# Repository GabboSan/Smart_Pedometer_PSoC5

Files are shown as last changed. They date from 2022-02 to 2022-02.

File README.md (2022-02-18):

# AY2022 I Project-1

Smart Pedometer project developed in a MSc Course of Politecnico di Milano:
Authors: 
1. Santicchi Gabriele
2. d'Arenzo Daniele 
3. Santini Matteo

In this work a PSoC CY8C5888LTI-LP097 communicates by I2C protocol with MPU9250, SSD1306, 24LC512 and by UART protocol with HC-06 Bluetooth.\
A PyQt5 GUI has been developed to upload sessions and set user credential.

## Aim of this Work

1. Implement a pedometer algorithm capable to identify and count steps online;
2. Exploit the over-threshold events interrupt of the MPU9250 to automatically wake up the device from sleep; go to sleep mode when no motion is detected for 1 minute;
3. Display in the GUI some statistics: total number of steps, average cadence, total activity time and the session path with respect to the origin (i.e. first 'step' detected);
4. Log the statistics of each session (i.e., of every walk detected) in the internal EEPROM of the PSoC;
5. Minimization of power consumption, by using powersaving functionalities of the PSoC (e.g., Alternate mode) as well as turining off external peripherals when not in use;
6. When connected via USB to the computer, the device can accept a data request and display/send the data stored into the EEPROM.

## MPU9250 and AHRS filtering

To keep track of the direction of the walk, the AHRS filter has been implemented to get a Roll-Pitch-Yaw estimate. As the filter needs the magnetometer measurements, the AK8963 is enabled and set as Slave on the I2C bus.
Each 2 seconds the pedometer algorithm compute the X and Y direction of the walk, by considering the RPY orientation of the device.
The two directions are saved as 16 bit and then saved into the cell of the EEPROM . Path is reconstructed by the PC through this relative coordinates system.

## EEPROM Session Data Structure

When no motion has been detected for 1 minute, the Wake-On-Motion (WOM) interrupt is enabled and session data are saved in the EEPROM with the following structure.\
**RESERVED CELL REGISTERS:**
* 0: Height;
* 1: UserID;
* 2: SessionID;
* 3-4: lastAddressEEPROM: to avoid data overwriting;

**CELL REGISTERS:**

From 24LC512 Datasheet, Read and Write max. operation number is limited to a Page size, which consist of 128 bytes. The Packets to be sent to the PC are structured as:

* UserID, SessionID, HEADER (0xFE,0xFF);
* dataXY: sequence of X and Y relative coordinates (in 16 bits) computed each 2 seconds;
* Number of Steps, TAIL (0xFF,0xFF);

## SSD1306 Display

The SSD1306 communicates by I2C with the Master. It displays the total step counter and the current speed (in cm/s) each 2 seconds. When the device enters in Sleep mode, the display is turned off.

## Final PCB ad Case
<p float="left">
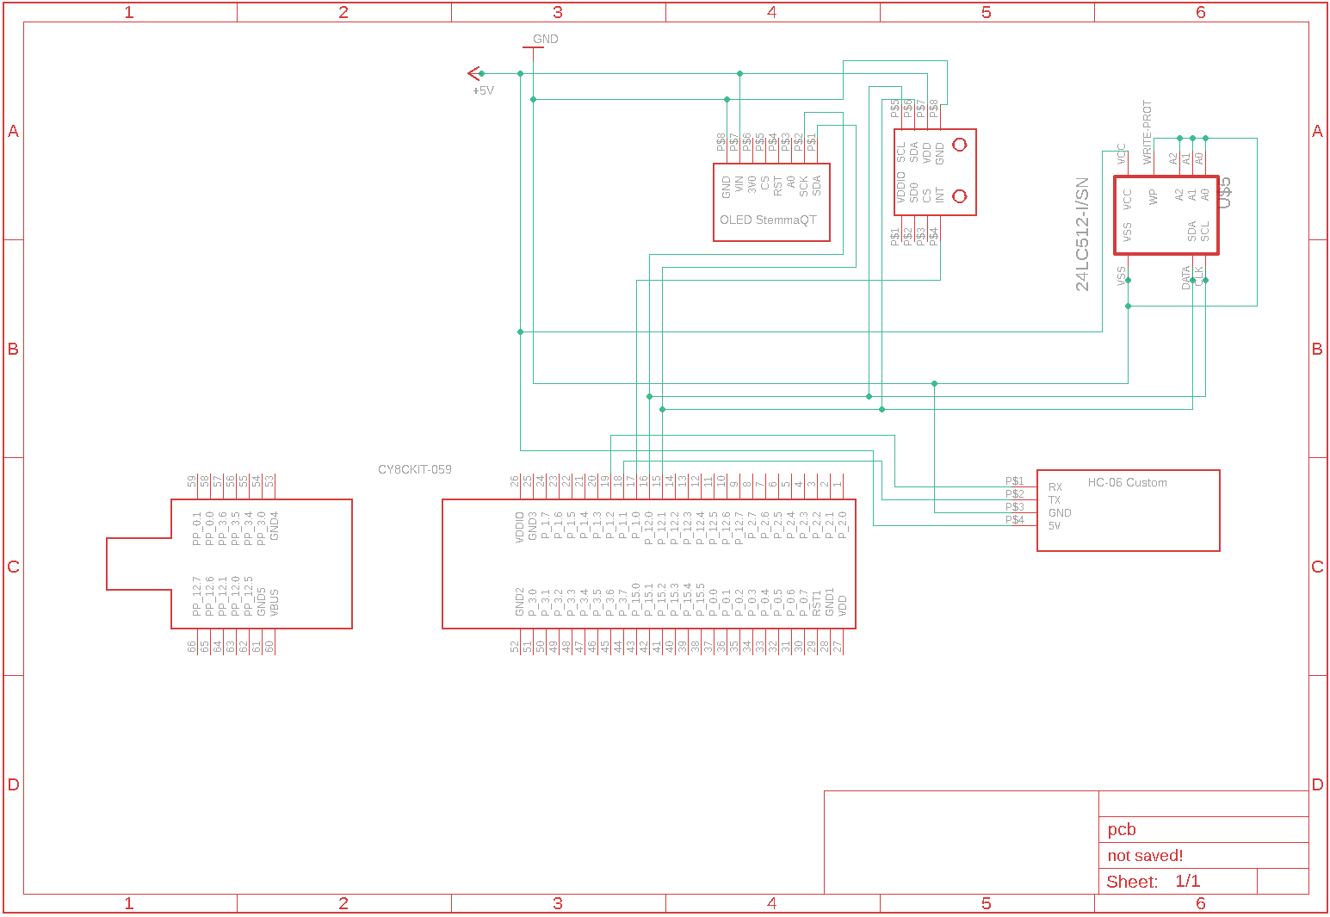
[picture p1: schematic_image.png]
  
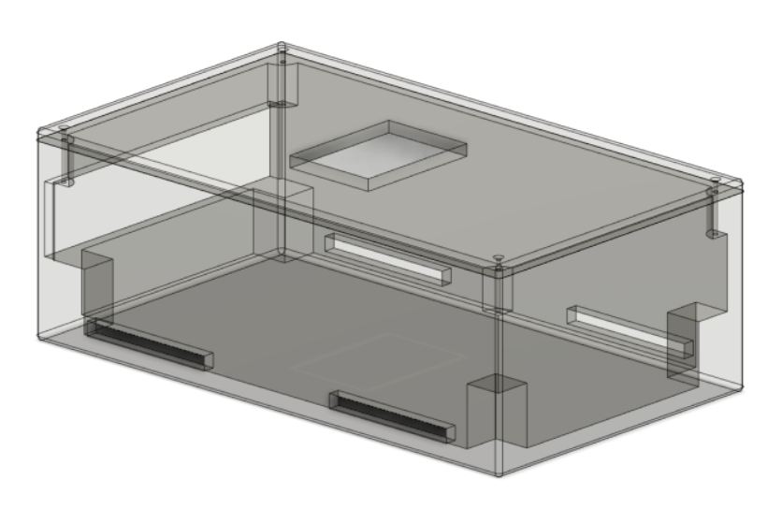
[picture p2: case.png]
   
</p>

# Guide

## Device Guide

Device must be put parallel to the calf fibers in order to get meaningful information about the orientation. During a Session, the Step counter and the Current speed are updated each 2 seconds on the SSD1306 display.\
A session starts when the device is powered, and ends when no motion has been detected for more than 1 minute. Then, the session is saved into the memory and the device enter in sleep mode until detection of futher N steps.

## GUI Guide

While running the GUI, the Device must be connected either by USB or Bluetooth. Even if an automatic scan of ports is implemented, sometimes a manual selection of the COM is required.
To get meaningful information about the orientation, the calibration of the magnetometer is recommended (move the device along an eigth figure until the calibration is not finished).\
The GUI is organized in tabs:

* Sessions: see the statistics related to each session downloaded from the device;
* Live Viewer: see the Session path and the current 3D orientation of the device;
* Edit Profile: to create, delete and modify a user;
* Advanced Tool: monitor Accelerometer, Gyroscope and Magnetometer values in real-time.

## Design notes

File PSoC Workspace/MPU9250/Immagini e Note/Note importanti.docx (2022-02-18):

1. Mettere sensitivity dei vari sensori nel main.c → OK
2. Controllare UART: stampa dei valori non è a frequenza costante → OK: Non avevo collegato la INTERRUPT dell’MPU9250!!!
3. Capire come e se cambia frequenza dell’update (sample period? Non sembra cambiare) → MPU9250_SetSampleRateDivider OK
4. AHRS non funziona perché prima bisogna abilitare magnetometro
5. MaxSampleRate di ACC e GYRO: 1 KHz. MaxSampleRate di MAGN: 100 Hz -> plottare risultati ogni 0.01 s

Perché non il magnetometro non veniva abilitato?
A fine lettura dei dati del magn contenuti tra 0x03 e 0x08, da Datasheet è necessario leggere registro ST2 (0x09) per concludere la fase di reading (leggere datasheet). In generale, corretta procedura è:

1. Leggere dispositivi connessi all’I2C bus (Presenti sia MPU9250 che AK8963). Se non presente AK8963, controllare se nello start (vedi dopo) è presente la funzione MPU9250_EnableI2CBypass(), altrimenti aggiungerla
2. MPU9250_Start(), al cui interno è necessario abilitare il magn MPU9250_MAG_Enable():

void MPU9250_MAG_Enable(void) {

MPU9250_I2C_Write(AK8963_I2C_ADDRESS, 0x0B,

(MPU9250_I2C_Read(AK8963_I2C_ADDRESS, 0x0B) | 0x01)); // (reset CNTL2 0x0B --> all reg reset

// For self-test:

//MPU9250_I2C_Write(AK8963_I2C_ADDRESS, 0x0C,

// (MPU9250_I2C_Read(AK8963_I2C_ADDRESS, 0x0C) | 0x40)); // (set ASTC bit6 high --> selftest

CyDelay(10);

MPU9250_I2C_Write(AK8963_I2C_ADDRESS, MPU9250_MAG_CNTL1_REG, 0x0F); // Enter Fuse ROM access mode

CyDelay(10);

MPU9250_I2C_ReadMulti(AK8963_I2C_ADDRESS, 0x10, &raw_data_calib_magn[0], 3); // Read the x-, y-, and z-axis calibration values

mag_bias_factory[0] = (float)(raw_data_calib_magn[0] - 128) / 256. + 4.; // Return x-axis sensitivity adjustment values, etc.

mag_bias_factory[1] = (float)(raw_data_calib_magn[1] - 128) / 256. + 4.;

mag_bias_factory[2] = (float)(raw_data_calib_magn[2] - 128) / 256. + 4.;

MPU9250_I2C_Write(AK8963_I2C_ADDRESS, MPU9250_MAG_CNTL1_REG, 0x00); // Power down magnetometer

CyDelay(10);

// setting the MPU9250_MAG_CNTL1_REG:

// 0x00 = MAG off (default)

// 0x01 = MAG on (14-bit output)

// 0x02 = Continuous mode 1

// 0x11 = MAG on AND 16-bit output with SNGL_MODE(0x11-> 00010001)

// 0x12 = MAG on AND 16-bit output with CNT_MODE1, 8Hz (0x12-> 00010010)

// 0x16 = MAG on AND 16-bit output with CNT_MODE2, 100Hz (0x16-> 00010110)

MPU9250_I2C_Write(AK8963_I2C_ADDRESS, MPU9250_MAG_CNTL1_REG, 0x16); // MAG on AND 16-bit output

}

3. Dopo aver letto i dati del magnetometro (presenti nei registri 0x03 – 0x09), Leggere il registro ST2 per chiudere la lettura!!

MPU9250_I2C_ReadMulti(AK8963_I2C_ADDRESS, MPU9250_MAG_XOUT_H_REG, data + 12, 6);

end_trasmission = MPU9250_I2C_Read(AK8963_I2C_ADDRESS, 0x09); //ST2 register (role as data reading end register)

typedef enum {

/** ±2g accelerometer full scale range **/

MPU9250_Acc_FS_2g,

/** ±4g accelerometer full scale range **/

MPU9250_Acc_FS_4g,

/** ±8g accelerometer full scale range **/

MPU9250_Acc_FS_8g,

/** ±16g accelerometer full scale range **/

MPU9250_Acc_FS_16g

} MPU9250_Acc_FS;

//in init:

MPU9250_SetAccFS(MPU9250_Acc_FS_2g);

void MPU9250_SetAccFS(MPU9250_Acc_FS fs) {

// Write the new full scale value in the acc conf register

// We need to first read the current bits of the register

uint8_t temp = MPU9250_I2C_Read(MPU9250_I2C_ADDRESS, MPU9250_ACCEL_CONFIG_REG);

// Then, we clear bits [4:3]

temp &= ~MPU9250_ACC_FS_MASK;

// Lastly, we write the new byte to the register

MPU9250_I2C_Write(MPU9250_I2C_ADDRESS, MPU9250_ACCEL_CONFIG_REG, temp | ( fs << 3));

// We also need to update the scaling factor

switch(fs) {

case MPU9250_Acc_FS_2g:

acc_scale = MPU9250_G * 2.0f/pow(2,16)/2;

break;

case MPU9250_Acc_FS_4g:

acc_scale = MPU9250_G * 4.0f/pow(2,16)/2;

break;

case MPU9250_Acc_FS_8g:

acc_scale = MPU9250_G * 8.0f/pow(2,16)/2;

break;

case MPU9250_Acc_FS_16g:

acc_scale = MPU9250_G * 16.0f/pow(2,16)/2;

break;

}

}

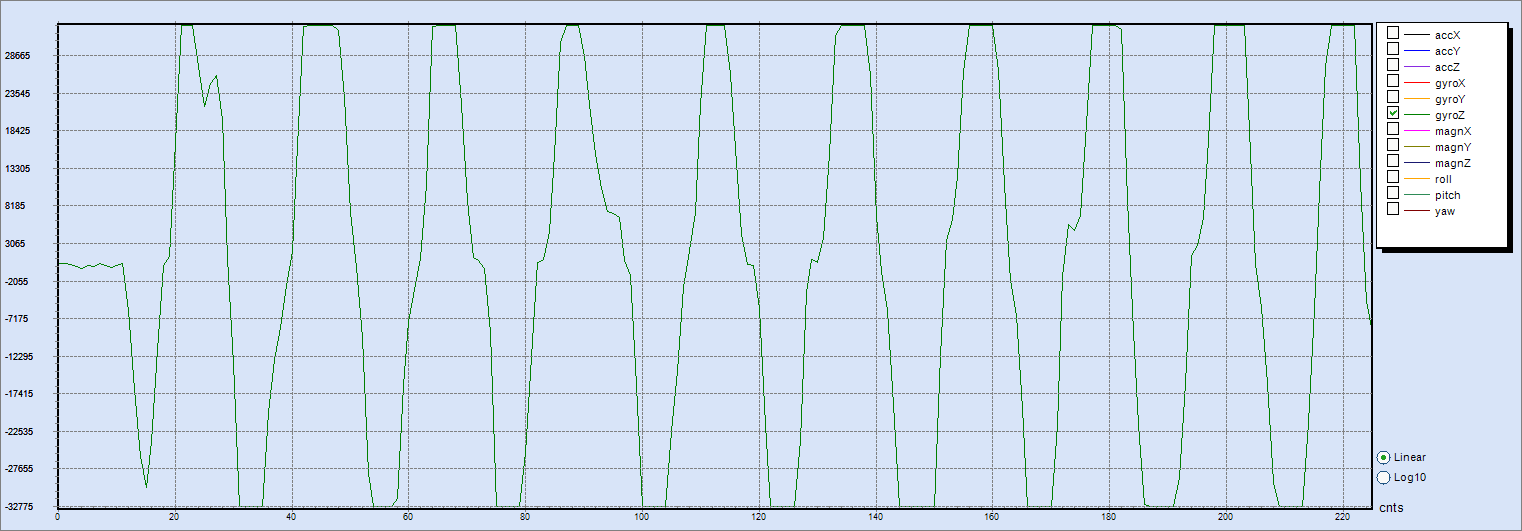
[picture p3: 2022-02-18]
PSoC Workspace/MPU9250/Bridge Control Panel/gyroZ_log_filterBW_5HZ.bmp

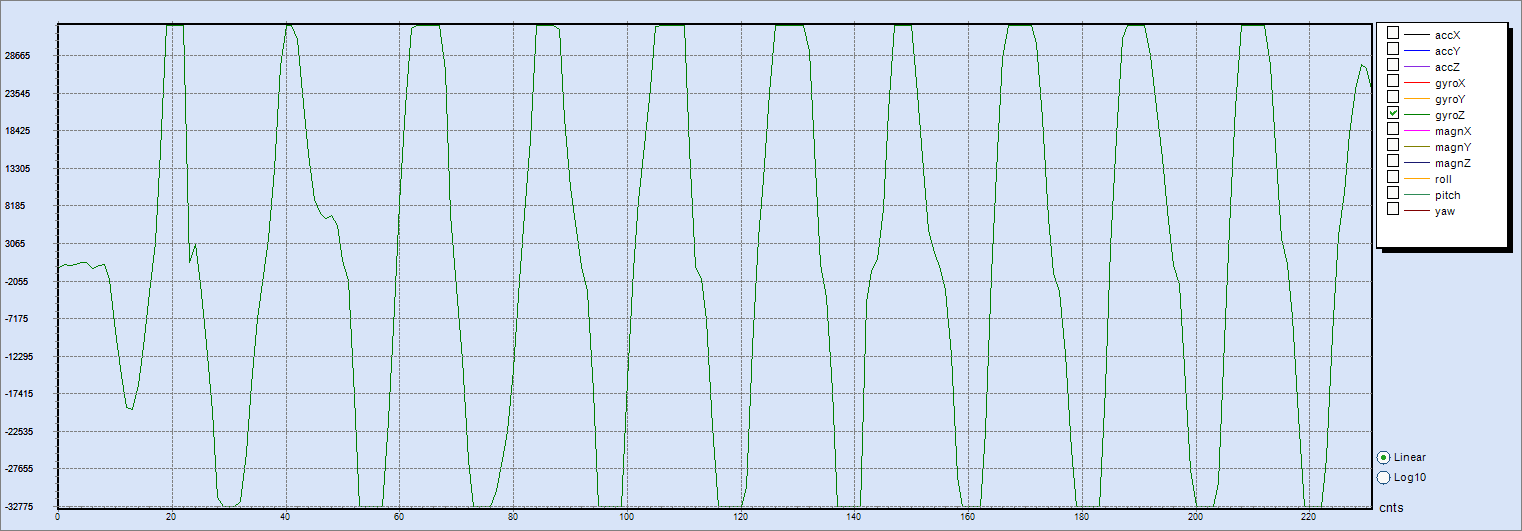
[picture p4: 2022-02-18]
PSoC Workspace/MPU9250/Bridge Control Panel/gyroZ_log_filterBW_41HZ.bmp

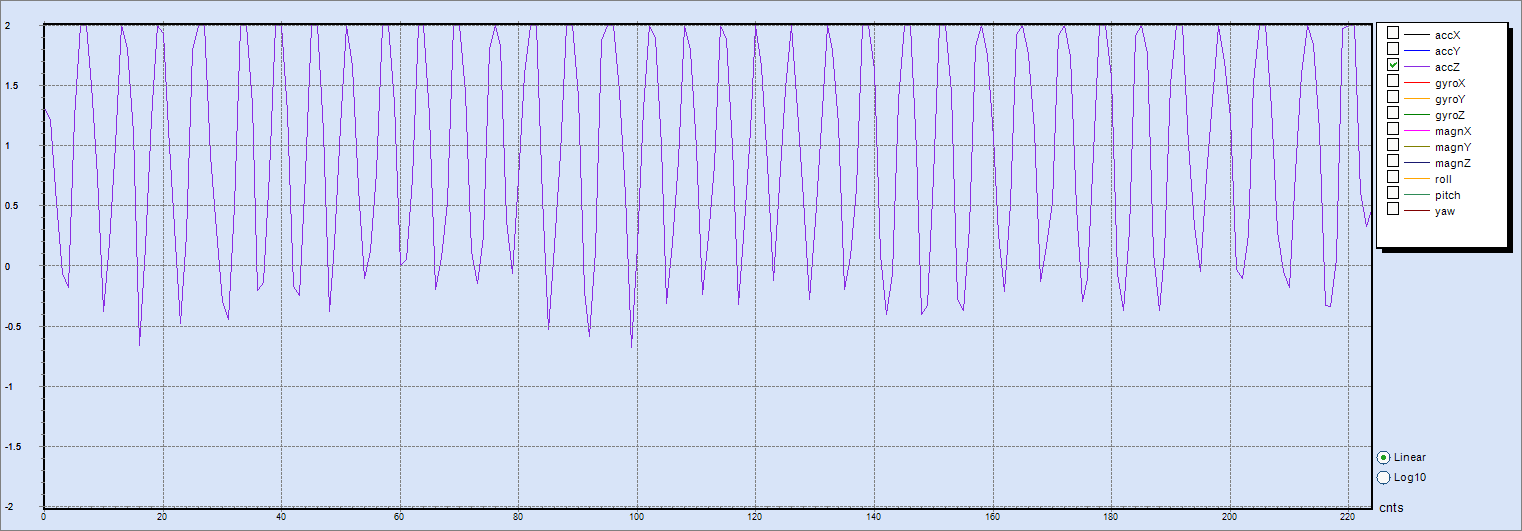
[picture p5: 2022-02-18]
PSoC Workspace/MPU9250/Bridge Control Panel/accZ_log_filterBW_1000HZ.bmp

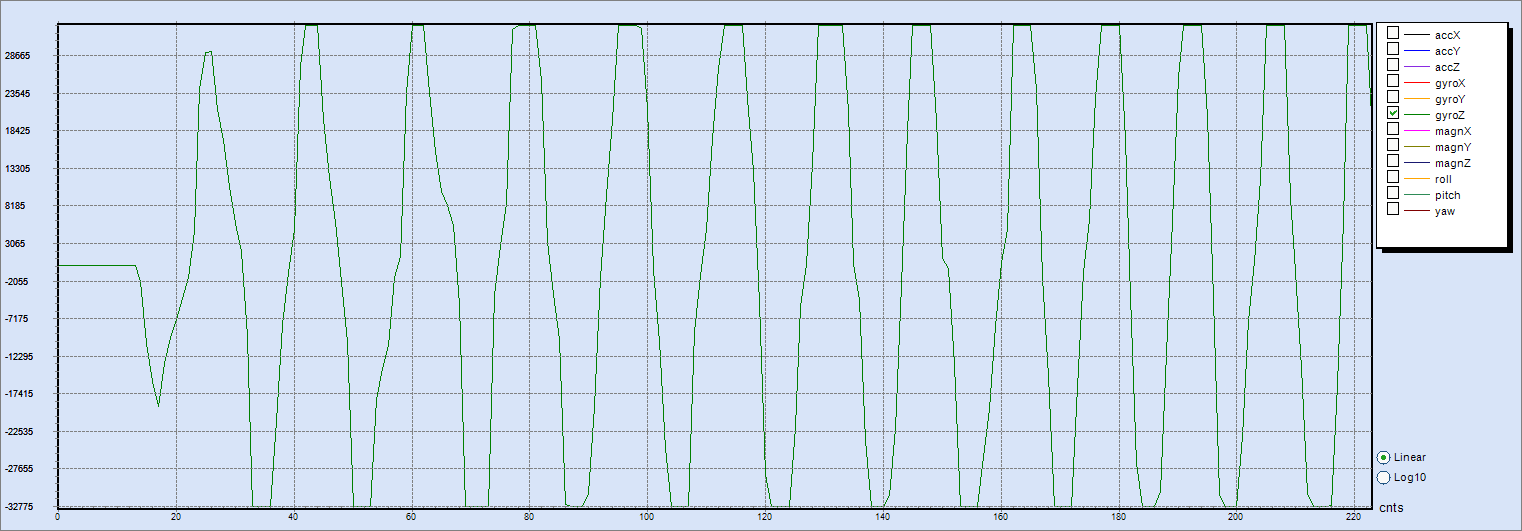
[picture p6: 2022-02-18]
PSoC Workspace/MPU9250/Bridge Control Panel/gyroZ_log_filterBW_8800HZ.bmp

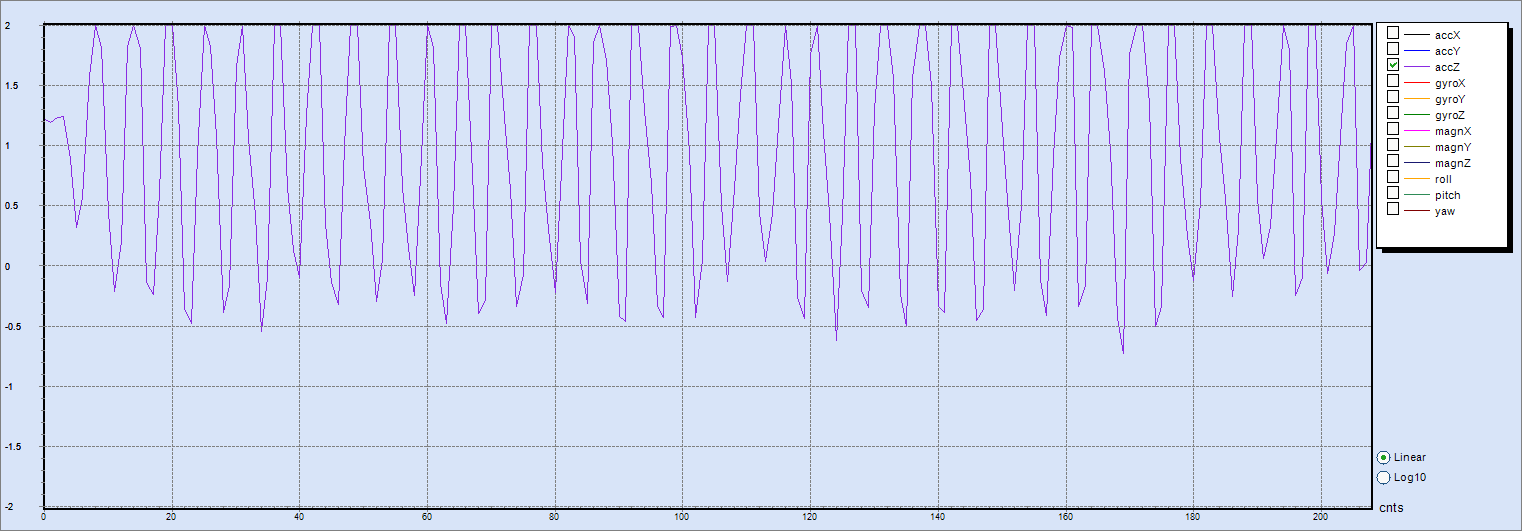
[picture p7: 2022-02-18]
PSoC Workspace/MPU9250/Bridge Control Panel/accZ_log_filterBW_5HZ.bmp

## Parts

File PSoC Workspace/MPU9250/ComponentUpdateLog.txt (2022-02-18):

Last Modified Date & Time: 12/05/2021 14:35:11

MPU920_I2C: MPU920_I2C.cydwr
	cy_boot [v5.70] to [v6.10]
	LIN_Dynamic [v4.0] to [v5.0]

MPU920_I2C: TopDesign.cysch
	MPU9250_ISR [v1.70] to [v1.71]

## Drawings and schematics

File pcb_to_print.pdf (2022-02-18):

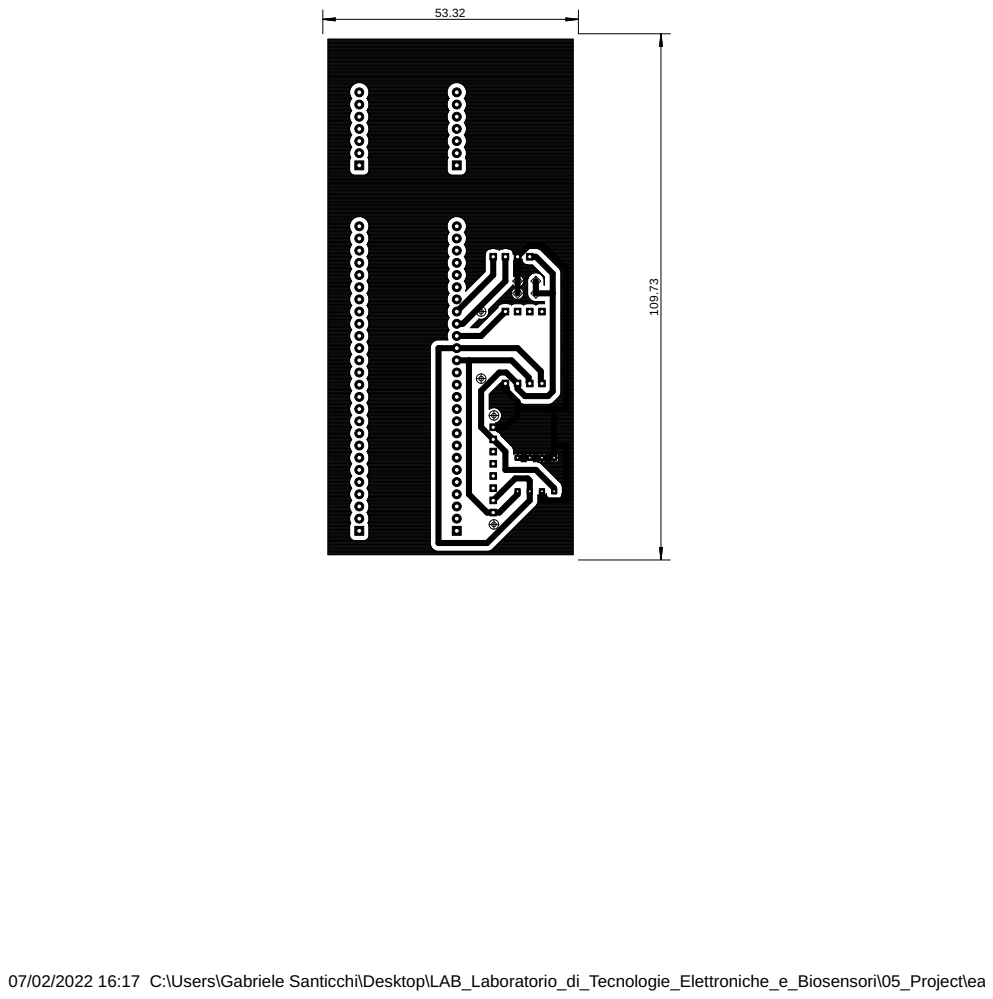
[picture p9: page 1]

07/02/2022 16:17 C:\Users\Gabriele Santicchi\Desktop\LAB_Laboratorio_di_Tecnologie_Elettroniche_e_Biosensori\05_Project\eagle-20220207T134615Z-001\eagle\LAB_Biosensors_project_pedometer\pcb.brd

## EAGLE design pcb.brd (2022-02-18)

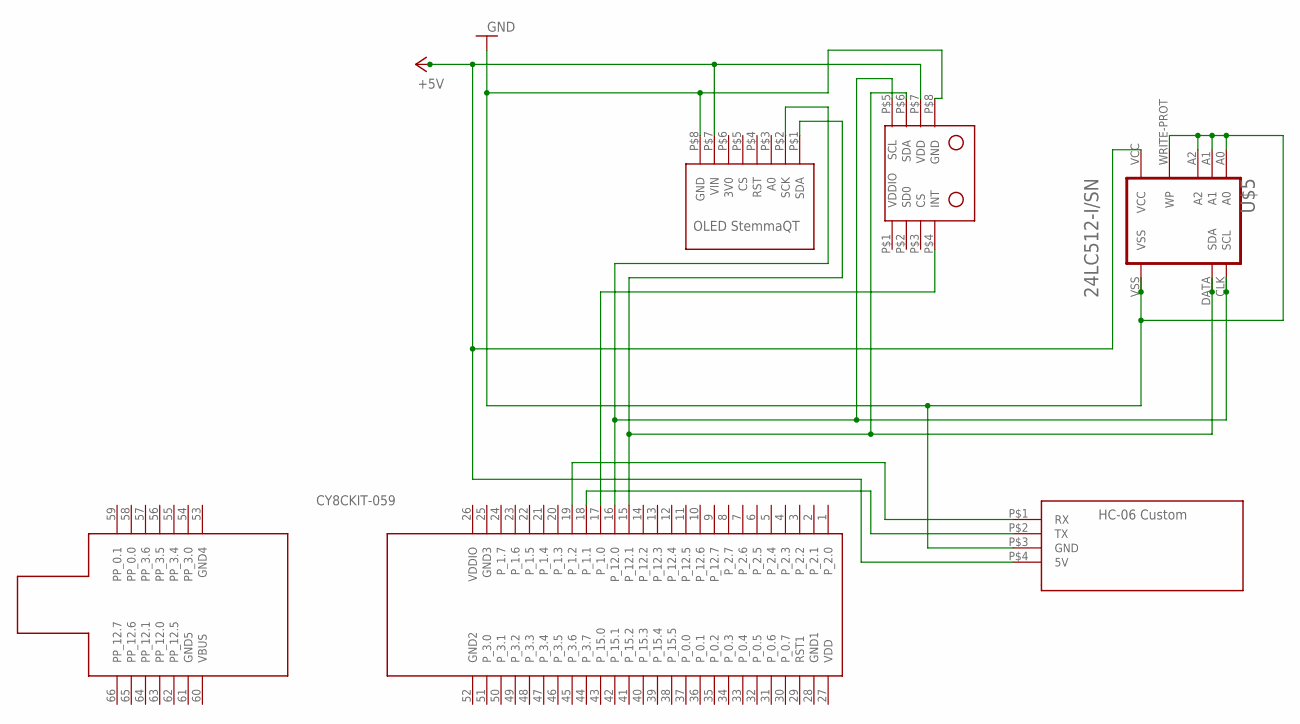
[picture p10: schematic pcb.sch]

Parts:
U$1: CY8CKIT-059
U$2: SSD1306_STEMMAQT_128X64; FTP_SSD1306_128X64_4PIN
U$3: HC-06_CUSTOM; FTP_HC-06_CUSTOM
U$4: MPU9250; FTP_MPU9650
U$5: 24LC512-I-CUSTOM

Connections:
+5V: U$2.P$7 (VIN), U$3.P$4 (5V), U$4.P$7 (VDD), U$5.VCC
GND: U$2.P$8 (GND), U$3.P$3 (GND), U$4.P$8 (GND), U$5.A0, U$5.A1, U$5.A2, U$5.VSS, U$5.WRITE-PROT (WP)
unnamed: U$1.19 (P_1.2), U$3.P$1 (RX)
unnamed: U$1.18 (P_1.1), U$3.P$2 (TX)
unnamed: U$1.16 (P_12.0), U$2.P$2 (SCK), U$4.P$5 (SCL), U$5.CLK (SCL)
unnamed: U$1.15 (P_12.1), U$2.P$1 (SDA), U$4.P$6 (SDA), U$5.DATA (SDA)
unnamed: U$1.17 (P_1.0), U$4.P$4 (INT)

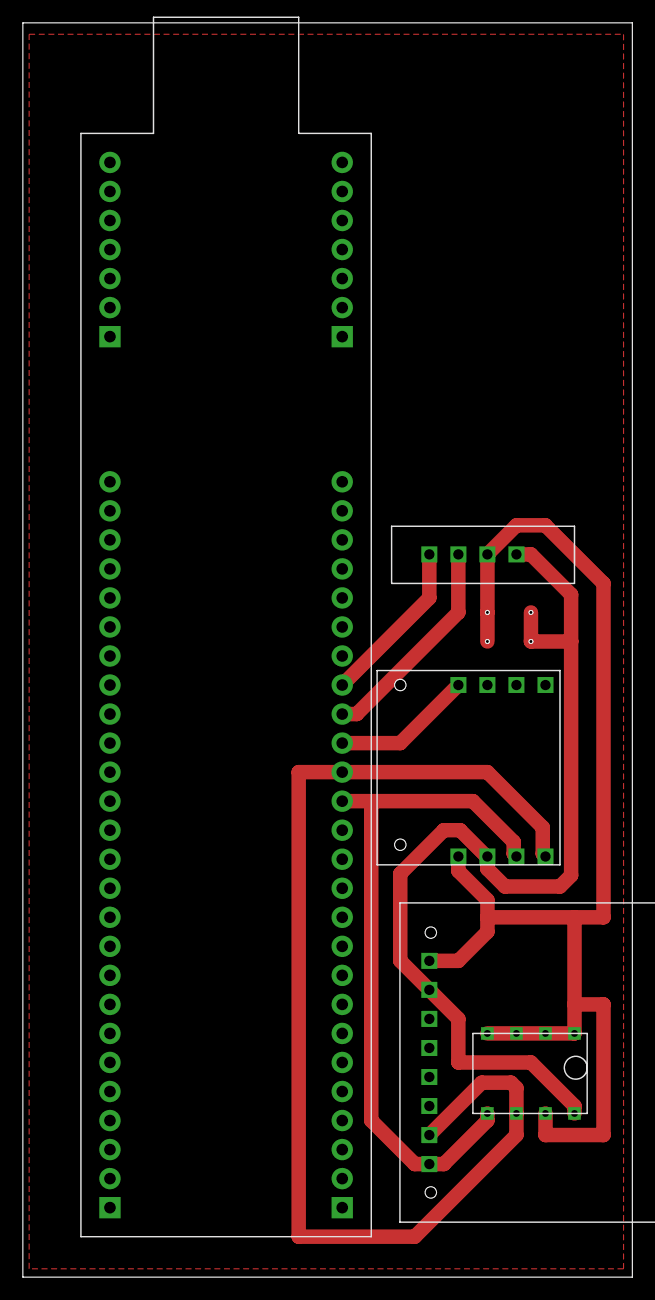
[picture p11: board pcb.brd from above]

Board: 2 copper layers, 53.3 x 109.7 mm, 5 parts (0 on the bottom side), 7 nets.

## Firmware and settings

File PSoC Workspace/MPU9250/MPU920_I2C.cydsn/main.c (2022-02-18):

/* ============================================
 *
 * @brief Main file for MPU9250 group1 project.
 * 
 * This is the main file to be used with the
 * MPU9250 group1 project. It sets up all the 
 * components required for the project.
 * 
 * @author group1
 * @year 2021-2022
 * ============================================
*/

// Include required header files
#include "project.h"
#include "MPU9250.h"
#include "MPU9250_RegMap.h"
#include "MPU9250_I2C.h"
#include "stdio.h"
#include "FusionCalibration.h"
#include "FusionCompass.h"
#include "FusionTypes.h"
#include "math.h"
#include "InterruptRoutines.h"
#include "functions.h"
#include "Threshold.h"
#include "stdbool.h"
#include "serial_worker.h"
#include "EEPROM/EEPROM.h"
//display
#include <stdlib.h>
#include "ssd1306.h"
#define DISPLAY_ADDRESS 0x3D 
#define WOMTHR 100
#define WOMFREQ 2
#define EEPROM_DIM 128

int16 state = -1; 
bool flag_calibration_todo = false;
bool bt_mode = false;

// *************** AHRS variables ****************
float32 acc[3], gyro[3], magn[3]; 
uint16_t n_samples = 0;
uint16_t n_samples_thr = 0;
uint16_t n_samples_2s = 0; 
extern uint16_t count_10ms_time;
extern uint16_t count_10ms_time_thr;
extern uint16_t count_10ms_time_2s;
extern uint16_t stride_total;
extern int16_t roll_curr;
extern int16_t pitch_curr;
extern int16_t yaw_curr;
MPU9250Setting setting;
extern uint8_t wom;
extern uint16_t eeprom_last_address;
extern uint8_t eeprom_data[EEPROM_DIM];
extern uint8_t idx_eeprom_data;

int main(void)
{   
            
    CyGlobalIntEnable; 
    
    // Start UART component
    UART_Debug_Start();
    UART_USB_Start();
    
    // Start I2C component
    I2C_MPU9250_Master_Start();
    CyDelay(1000);
    
    // *************** SETTING MPU9250 **************************
    
    setting.accel_fs_sel = A4G;
    setting.gyro_fs_sel = G500DPS;
    setting.mag_output_bits = M16BITS;
    setting.fifo_sample_rate = SMPL_100HZ;
    setting.gyro_fchoice = 0x03;
    setting.gyro_dlpf_cfg = DLPF_41HZ;
    setting.accel_fchoice = 0x01;
    setting.accel_dlpf_cfg = DLPFa_45HZ;

    //init MPU
    init_MPU();
    //init fusion
    Fusion_init();
    //start MPU ISR
    MPU9250_ISR_StartEx(MPU9250_DR_ISR);
    //timer ISR
    Timer_Start(); 
    Timer_Int_StartEx(Custom_ISR); 
    Timer_2_Start();
    //init display 
    display_init(DISPLAY_ADDRESS); 

    //reset all memory
    /*uint8_t zeros[128]={0};
    EEPROM_Write(5,zeros,123);
    CyDelay(100);
    for (uint16 i=1;i<512;i++){
        EEPROM_Write(i*128,zeros,128);
        CyDelay(100);
    }*/
    
    // get last written EEPROM address 
    uint8_t address[2];
    address[0]=EEPROM_Read123(3);   //MSB
    address[1]=EEPROM_Read123(4);   //LSB
    eeprom_last_address = (address[0] << 8) | (address[1] & 0xFF);
    

    MPU9250_StartWom(WOMTHR, WOMFREQ);
    
    /*========================================
    STATE -1: idle, possible operations:
        - read incoming serial messages
        - enable power saving features
    STATE 0: calibration
    STATE 1: data_processing
    ========================================*/
    
    for(;;)
    {
        switch(state)
        {
            case -1: //idle
                serial_check_HT();  //check for new serial messages
                if( wom==1){
                    SaveSession();
                    wom=0;
                }
                break;
            
            case 0:  // magnetometer calibration
                MagCalibration_acquisition(magn);
                state = -1;  // set idle mode
                break;
                
            case 1:  //data processing
                Connection_Led_Write(1);
                AHRS_filtering(acc, gyro, magn);
                Threshold_algo(acc, &count_10ms_time, &count_10ms_time_thr, &count_10ms_time_2s);
                state = -1;  // set idle mode
                break;
        }       
    }
}

/* [] END OF FILE */

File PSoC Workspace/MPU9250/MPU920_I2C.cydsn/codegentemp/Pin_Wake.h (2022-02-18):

/*******************************************************************************
* File Name: Pin_Wake.h  
* Version 2.20
*
* Description:
*  This file contains Pin function prototypes and register defines
*
* Note:
*
********************************************************************************
* Copyright 2008-2015, Cypress Semiconductor Corporation.  All rights reserved.
* You may use this file only in accordance with the license, terms, conditions, 
* disclaimers, and limitations in the end user license agreement accompanying 
* the software package with which this file was provided.
*******************************************************************************/

#if !defined(CY_PINS_Pin_Wake_H) /* Pins Pin_Wake_H */
#define CY_PINS_Pin_Wake_H

#include "cytypes.h"
#include "cyfitter.h"
#include "cypins.h"
#include "Pin_Wake_aliases.h"

/* APIs are not generated for P15[7:6] */
#if !(CY_PSOC5A &&\
	 Pin_Wake__PORT == 15 && ((Pin_Wake__MASK & 0xC0) != 0))


/***************************************
*        Function Prototypes             
***************************************/    

/**
* \addtogroup group_general
* @{
*/
void    Pin_Wake_Write(uint8 value);
void    Pin_Wake_SetDriveMode(uint8 mode);
uint8   Pin_Wake_ReadDataReg(void);
uint8   Pin_Wake_Read(void);
void    Pin_Wake_SetInterruptMode(uint16 position, uint16 mode);
uint8   Pin_Wake_ClearInterrupt(void);
/** @} general */

/***************************************
*           API Constants        
***************************************/
/**
* \addtogroup group_constants
* @{
*/
    /** \addtogroup driveMode Drive mode constants
     * \brief Constants to be passed as "mode" parameter in the Pin_Wake_SetDriveMode() function.
     *  @{
     */
        #define Pin_Wake_DM_ALG_HIZ         PIN_DM_ALG_HIZ
        #define Pin_Wake_DM_DIG_HIZ         PIN_DM_DIG_HIZ
        #define Pin_Wake_DM_RES_UP          PIN_DM_RES_UP
        #define Pin_Wake_DM_RES_DWN         PIN_DM_RES_DWN
        #define Pin_Wake_DM_OD_LO           PIN_DM_OD_LO
        #define Pin_Wake_DM_OD_HI           PIN_DM_OD_HI
        #define Pin_Wake_DM_STRONG          PIN_DM_STRONG
        #define Pin_Wake_DM_RES_UPDWN       PIN_DM_RES_UPDWN
    /** @} driveMode */
/** @} group_constants */
    
/* Digital Port Constants */
#define Pin_Wake_MASK               Pin_Wake__MASK
#define Pin_Wake_SHIFT              Pin_Wake__SHIFT
#define Pin_Wake_WIDTH              1u

/* Interrupt constants */
#if defined(Pin_Wake__INTSTAT)
/**
* \addtogroup group_constants
* @{
*/
    /** \addtogroup intrMode Interrupt constants
     * \brief Constants to be passed as "mode" parameter in Pin_Wake_SetInterruptMode() function.
     *  @{
     */
        #define Pin_Wake_INTR_NONE      (uint16)(0x0000u)
        #define Pin_Wake_INTR_RISING    (uint16)(0x0001u)
        #define Pin_Wake_INTR_FALLING   (uint16)(0x0002u)
        #define Pin_Wake_INTR_BOTH      (uint16)(0x0003u) 
    /** @} intrMode */
/** @} group_constants */

    #define Pin_Wake_INTR_MASK      (0x01u) 
#endif /* (Pin_Wake__INTSTAT) */


/***************************************
*             Registers        
***************************************/

/* Main Port Registers */
/* Pin State */
#define Pin_Wake_PS                     (* (reg8 *) Pin_Wake__PS)
/* Data Register */
#define Pin_Wake_DR                     (* (reg8 *) Pin_Wake__DR)
/* Port Number */
#define Pin_Wake_PRT_NUM                (* (reg8 *) Pin_Wake__PRT) 
/* Connect to Analog Globals */                                                  
#define Pin_Wake_AG                     (* (reg8 *) Pin_Wake__AG)                       
/* Analog MUX bux enable */
#define Pin_Wake_AMUX                   (* (reg8 *) Pin_Wake__AMUX) 
/* Bidirectional Enable */                                                        
#define Pin_Wake_BIE                    (* (reg8 *) Pin_Wake__BIE)
/* Bit-mask for Aliased Register Access */
#define Pin_Wake_BIT_MASK               (* (reg8 *) Pin_Wake__BIT_MASK)
/* Bypass Enable */
#define Pin_Wake_BYP                    (* (reg8 *) Pin_Wake__BYP)
/* Port wide control signals */                                                   
#define Pin_Wake_CTL                    (* (reg8 *) Pin_Wake__CTL)
/* Drive Modes */
#define Pin_Wake_DM0                    (* (reg8 *) Pin_Wake__DM0) 
#define Pin_Wake_DM1                    (* (reg8 *) Pin_Wake__DM1)
#define Pin_Wake_DM2                    (* (reg8 *) Pin_Wake__DM2) 
/* Input Buffer Disable Override */
#define Pin_Wake_INP_DIS                (* (reg8 *) Pin_Wake__INP_DIS)
/* LCD Common or Segment Drive */
#define Pin_Wake_LCD_COM_SEG            (* (reg8 *) Pin_Wake__LCD_COM_SEG)
/* Enable Segment LCD */
#define Pin_Wake_LCD_EN                 (* (reg8 *) Pin_Wake__LCD_EN)
/* Slew Rate Control */
#define Pin_Wake_SLW                    (* (reg8 *) Pin_Wake__SLW)
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

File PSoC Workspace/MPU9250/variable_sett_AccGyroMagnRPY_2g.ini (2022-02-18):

[VARIABLES_SETTINGS]
PACKET=1
SCROLL=0
AXIS_X_TYPE=0
AUTO_RANGE_OF_AXIS_Y=0
AXIS_Y_MIN=-32775
AXIS_Y_MAX=32775
SHOW_FLAGS=0
AMPLITUDE=10
THICKNESS=1
VARIABLES=32
Var1.Number=1
Var1.Active=True
Var1.VariableName=accX
Var1.Type=int
Var1.Sign=True
Var1.Scale=6.1E-05
Var1.Offset=0
Var1.Color=Black
Var2.Number=2
Var2.Active=True
Var2.VariableName=accY
Var2.Type=int
Var2.Sign=True
Var2.Scale=6.1E-05
Var2.Offset=0
Var2.Color=Blue
Var3.Number=3
Var3.Active=True
Var3.VariableName=accZ
Var3.Type=int
Var3.Sign=True
Var3.Scale=6.1E-05
Var3.Offset=0
Var3.Color=BlueViolet
Var4.Number=4
Var4.Active=True
Var4.VariableName=gyroX
Var4.Type=int
Var4.Sign=True
Var4.Scale=1
Var4.Offset=0
Var4.Color=Red
Var5.Number=5
Var5.Active=True
Var5.VariableName=gyroY
Var5.Type=int
Var5.Sign=True
Var5.Scale=1
Var5.Offset=0
Var5.Color=Orange
Var6.Number=6
Var6.Active=True
Var6.VariableName=gyroZ
Var6.Type=int
Var6.Sign=True
Var6.Scale=1
Var6.Offset=0
Var6.Color=LawnGreen
Var7.Number=7
Var7.Active=True
Var7.VariableName=magnX
Var7.Type=int
Var7.Sign=True
Var7.Scale=1
Var7.Offset=0
Var7.Color=Magenta
Var8.Number=8
Var8.Active=True
Var8.VariableName=magnY
Var8.Type=int
Var8.Sign=True
Var8.Scale=1
Var8.Offset=0
Var8.Color=Olive
Var9.Number=9
Var9.Active=True
Var9.VariableName=magnZ
Var9.Type=int
Var9.Sign=True
Var9.Scale=1
Var9.Offset=0
Var9.Color=MidnightBlue
Var10.Number=10
Var10.Active=True
Var10.VariableName=roll
Var10.Type=int
Var10.Sign=True
Var10.Scale=1
Var10.Offset=0
Var10.Color=Orange
Var11.Number=11
Var11.Active=True
Var11.VariableName=pitch
Var11.Type=int
Var11.Sign=True
Var11.Scale=1
Var11.Offset=0
Var11.Color=SeaGreen
Var12.Number=12
Var12.Active=True
Var12.VariableName=yaw
Var12.Type=int
Var12.Sign=True
Var12.Scale=1
Var12.Offset=0
Var12.Color=Maroon
Var13.Number=13
Var13.Active=False
Var13.VariableName=Var13
Var13.Type=byte
Var13.Sign=False
Var13.Scale=1
Var13.Offset=0
Var13.Color=OrangeRed
Var14.Number=14
Var14.Active=False
Var14.VariableName=Var14
Var14.Type=byte
Var14.Sign=False
Var14.Scale=1
Var14.Offset=0
Var14.Color=Purple
Var15.Number=15
Var15.Active=False
Var15.VariableName=Var15
Var15.Type=byte
Var15.Sign=False
Var15.Scale=1
Var15.Offset=0
Var15.Color=SaddleBrown
Var16.Number=16
Var16.Active=False
Var16.VariableName=Var16
Var16.Type=byte
Var16.Sign=False
Var16.Scale=1
Var16.Offset=0
Var16.Color=Gray
Var17.Number=17
Var17.Active=False
Var17.VariableName=Var17
Var17.Type=byte
Var17.Sign=False
Var17.Scale=1
Var17.Offset=0
Var17.Color=Black
Var18.Number=18
Var18.Active=False
Var18.VariableName=Var18
Var18.Type=byte
Var18.Sign=False
Var18.Scale=1
Var18.Offset=0
Var18.Color=Blue
Var19.Number=19
Var19.Active=False
Var19.VariableName=Var19
Var19.Type=byte
Var19.Sign=False
Var19.Scale=1
Var19.Offset=0
Var19.Color=Lime
Var20.Number=20
Var20.Active=False
Var20.VariableName=Var20
Var20.Type=byte
Var20.Sign=False
Var20.Scale=1
Var20.Offset=0
Var20.Color=Red
Var21.Number=21
Var21.Active=False
Var21.VariableName=Var21
Var21.Type=byte
Var21.Sign=False
Var21.Scale=1
Var21.Offset=0
Var21.Color=BlueViolet
Var22.Number=22
Var22.Active=False
Var22.VariableName=Var22
Var22.Type=byte
Var22.Sign=False
Var22.Scale=1
Var22.Offset=0
Var22.Color=LawnGreen
Var23.Number=23
Var23.Active=False
Var23.VariableName=Var23
Var23.Type=byte
Var23.Sign=False
Var23.Scale=1
Var23.Offset=0
Var23.Color=Magenta
Var24.Number=24
Var24.Active=False
Var24.VariableName=Var24
Var24.Type=byte
Var24.Sign=False
Var24.Scale=1
Var24.Offset=0
Var24.Color=Olive
Var25.Number=25
Var25.Active=False
Var25.VariableName=Var25
Var25.Type=byte
Var25.Sign=False
Var25.Scale=1
Var25.Offset=0
Var25.Color=MidnightBlue
Var26.Number=26
Var26.Active=False
Var26.VariableName=Var26
Var26.Type=byte
Var26.Sign=False
Var26.Scale=1
Var26.Offset=0
Var26.Color=Orange
Var27.Number=27
Var27.Active=False
Var27.VariableName=Var27
Var27.Type=byte
Var27.Sign=False
Var27.Scale=1
Var27.Offset=0
Var27.Color=SeaGreen
Var28.Number=28
Var28.Active=False
Var28.VariableName=Var28
Var28.Type=byte
Var28.Sign=False
Var28.Scale=1
Var28.Offset=0
Var28.Color=Maroon
Var29.Number=29
Var29.Active=False
Var29.VariableName=Var29
Var29.Type=byte
Var29.Sign=False
Var29.Scale=1
Var29.Offset=0
Var29.Color=OrangeRed
Var30.Number=30
Var30.Active=False
Var30.VariableName=Var30
Var30.Type=byte
Var30.Sign=False
Var30.Scale=1
Var30.Offset=0
Var30.Color=Purple
Var31.Number=31
Var31.Active=False
Var31.VariableName=Var31
Var31.Type=byte
Var31.Sign=False
Var31.Scale=1
Var31.Offset=0
Var31.Color=SaddleBrown
Var32.Number=32
Var32.Active=False
Var32.VariableName=Var32
Var32.Type=byte
Var32.Sign=False
Var32.Scale=1
Var32.Offset=0
Var32.Color=Gray
[FLAGS_SETTINGS]
FLAGS=16
Flag1.Number=1
Flag1.Active=False
Flag1.VariableName=accX
Flag1.FlagName=gf0
Flag1.BitMask=00000000
Flag1.Inversion=False
Flag1.Visible=False
Flag1.Position=0
Flag1.Color=Blue
Flag2.Number=2
Flag2.Active=False
Flag2.VariableName=accX
Flag2.FlagName=gf1
Flag2.BitMask=00000000
Flag2.Inversion=False
Flag2.Visible=False
Flag2.Position=0
Flag2.Color=BlueViolet
Flag3.Number=3
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
